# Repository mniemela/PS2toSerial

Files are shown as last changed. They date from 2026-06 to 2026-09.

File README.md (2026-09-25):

# PS2toSerial
PS/2 to serial converter using ATtiny4313 and MAX232. There are plenty of similar projects, but almost all of them are external, so here's my internal version
which draws power from floppy power connector.

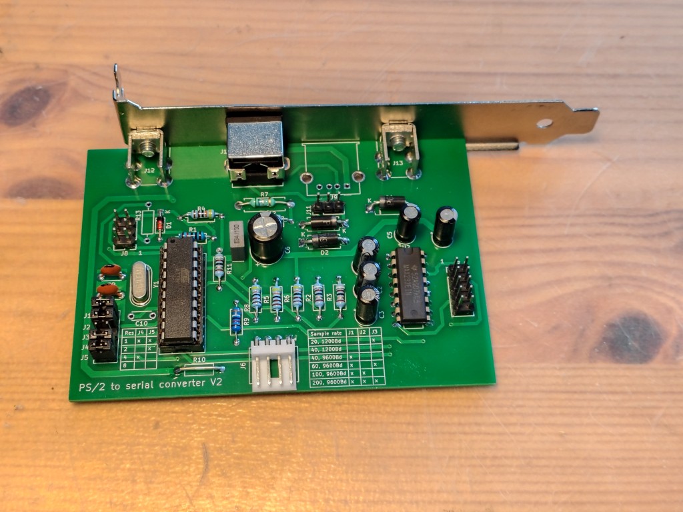
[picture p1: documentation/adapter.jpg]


## Description

This does essentially the same thing as other PS/2 to serial adapters: it interfaces with PS/2 mouse, and pretends to be a serial mouse to the computer.

It has following features:
* Support for normal 1200 baud serial, or 9600 baud high speed mode
* Support for wheel mouse
* Sample rate is selected from 20/40/60/100/200 with jumpers. For higher than 40, 9600 baud serial is needed.
* Resolution is configured with jumpers
* Option for USB A connector, so no need for a passive USB->PS/2 -adapter
* Option for PS/2 connector is also provided
* Supports hotplugging
* Crystal oscillator for ensuring accurate baud rate
* TVS diodes for ESD protection
* Overcurrent protection using ATtiny4313's onboard analog comparator and a P-type MOSFET as a switch
* No SMD components, so it's easy to assemble
* Programming via SPI header
* Supports combining movement packets in 1200 baud mode as a KVM workaround

Jumpers J1 sets baud rate, closed is high speed mode. J2 and J3 sets sample rate as described in silkscreen, and J4 and J4 set resolution.

Using 9600 baud serial speed requires modified mouse drivers, which can be found for example from this project:
https://github.com/LimeProgramming/USB-serial-mouse-adapter/tree/main

There are footprints for both USB-A and mini-DIN6 or PS/2 connector, only one of them should be populated.

## KVM issues

Some KVM switches ignore commands to set sample rate. The adapter tries to set baud rate to configured value, but the KVM will ignore 
it and packets are received faster than they can be sent to PC. As a new feature, this adapter combines data in movement packets
so that they don't have to be dropped.

Also, some KVM switches randomly reset in middle of normal operation. There's a workaround for this as well.

## Technical details

ATtiny has both hardware USART and Universal Serial Interface or USI, which is readily adaptable to PS/2, so there's only minimal need for bit banging. USI provides 
start condition detector with interrupt and counter (increased at PS/2's clock rising and falling edge) overflow interrupt, which removes need for polling. Instead
of sampling data on falling clock edge, this adapter uses rising edge as all the devices I have measured change data line state closer to falling than rising edge.
In particular, with a KVM switch this was within as little as 3µs from falling edge!

Resistors R8 and R9 form voltage divider for analog comparator positive input pin. R7 is used as a shunt resistor for current detection, voltage after it goes to
comparator's negative input pin. Comparator's output is monitored by interrupt from timer 0 every 100µs, and if there's overcurrent for 1ms, power to PS/2 is shut down.

RTS and DTR signals to pins PB2 and PB3 are monitored with pin change interrupt. When either of them goes down and then back up, mouse detection characters are sent if
mouse is connected.

Normally PS/2 host doesn't know whether mouse is disconnected or is just still, so the adapter polls mouse by sending command enable data reporting or 0xF4 every two
seconds. If mouse is connected, it replys with an ACK or 0xFA, if it's disconnected, there's no clock signal which is detected.

Some KVM switches randomly reset in the middle of normal operation and send 0xAA and 0x00 as during boot, then stopping to send movement data. This adapter attempts
to detect this situation and recover from it.

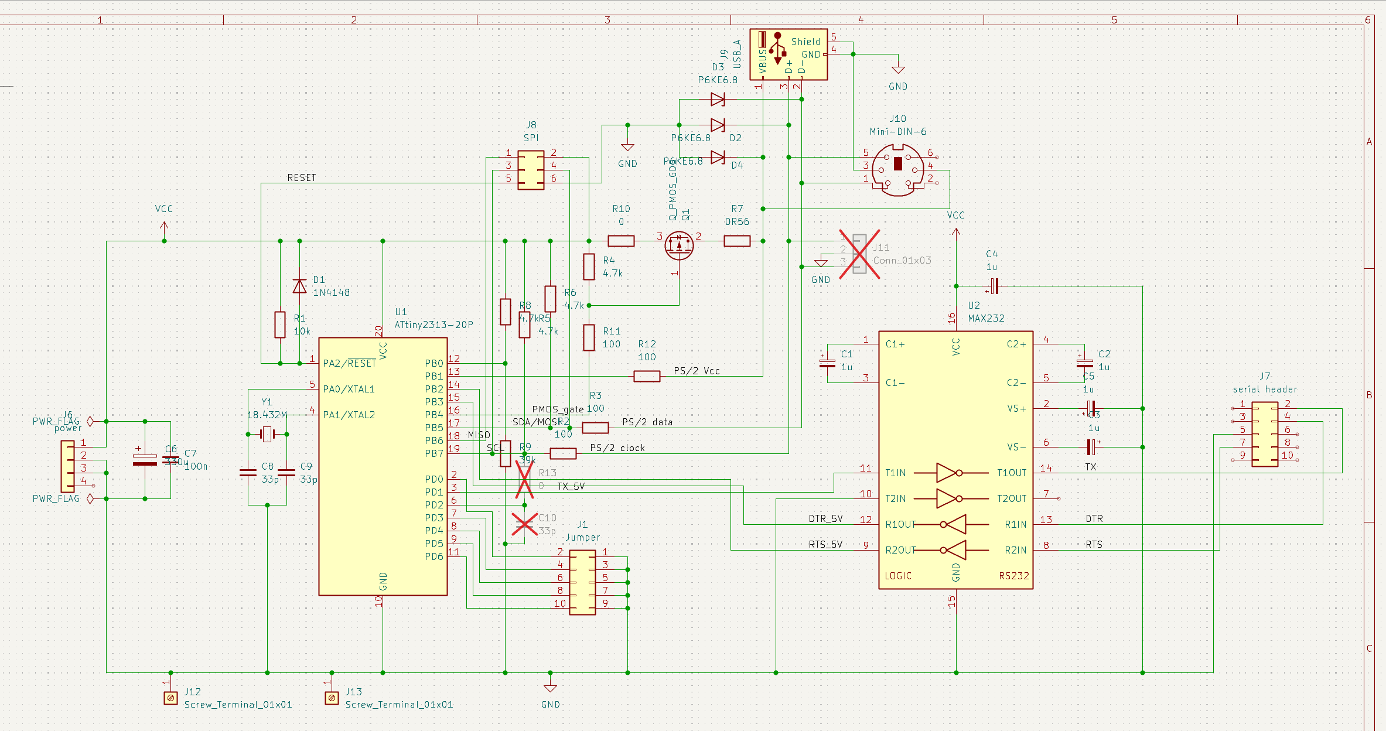
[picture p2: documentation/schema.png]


\
**BOM of specific components:**
| Ref. | Part. no. | Note |
|---|---|---|
| Q1 | MTD20P06HDL | Any DPAK logic level P-channel enhancement-type MOSFET with similar pinout will work. |
| U1 | ATtiny4313-PU | Microcontroller |
| U2 | MAX232 | RS-232 transceiver |
| R7 | 560mΩ resistor | Anything with max. dissipation > 600mW will work. |
| Y1 | AS-18.432-20 | Other frequencies up to 20M can be used, but will require modifications to software. |
| D2-D4 | P6KE6.8 | TVS diode with 5.8V working voltage |
| J10 | MDC-206 | mini-DIN6 connector |
| J12, J13 | AMT0440051DB0000G | M4 screw terminal |
| C6 | ??? | Exact value of this capacitor isn't important. |

## Building software and MCU fuse settings

This has been built with Microchip studio, currently there's no Makefile for other toolchains. When programming the MCU, fuses must also be set. Correct setting for
high fuse is 0xDF and for low fuse 0xFF.

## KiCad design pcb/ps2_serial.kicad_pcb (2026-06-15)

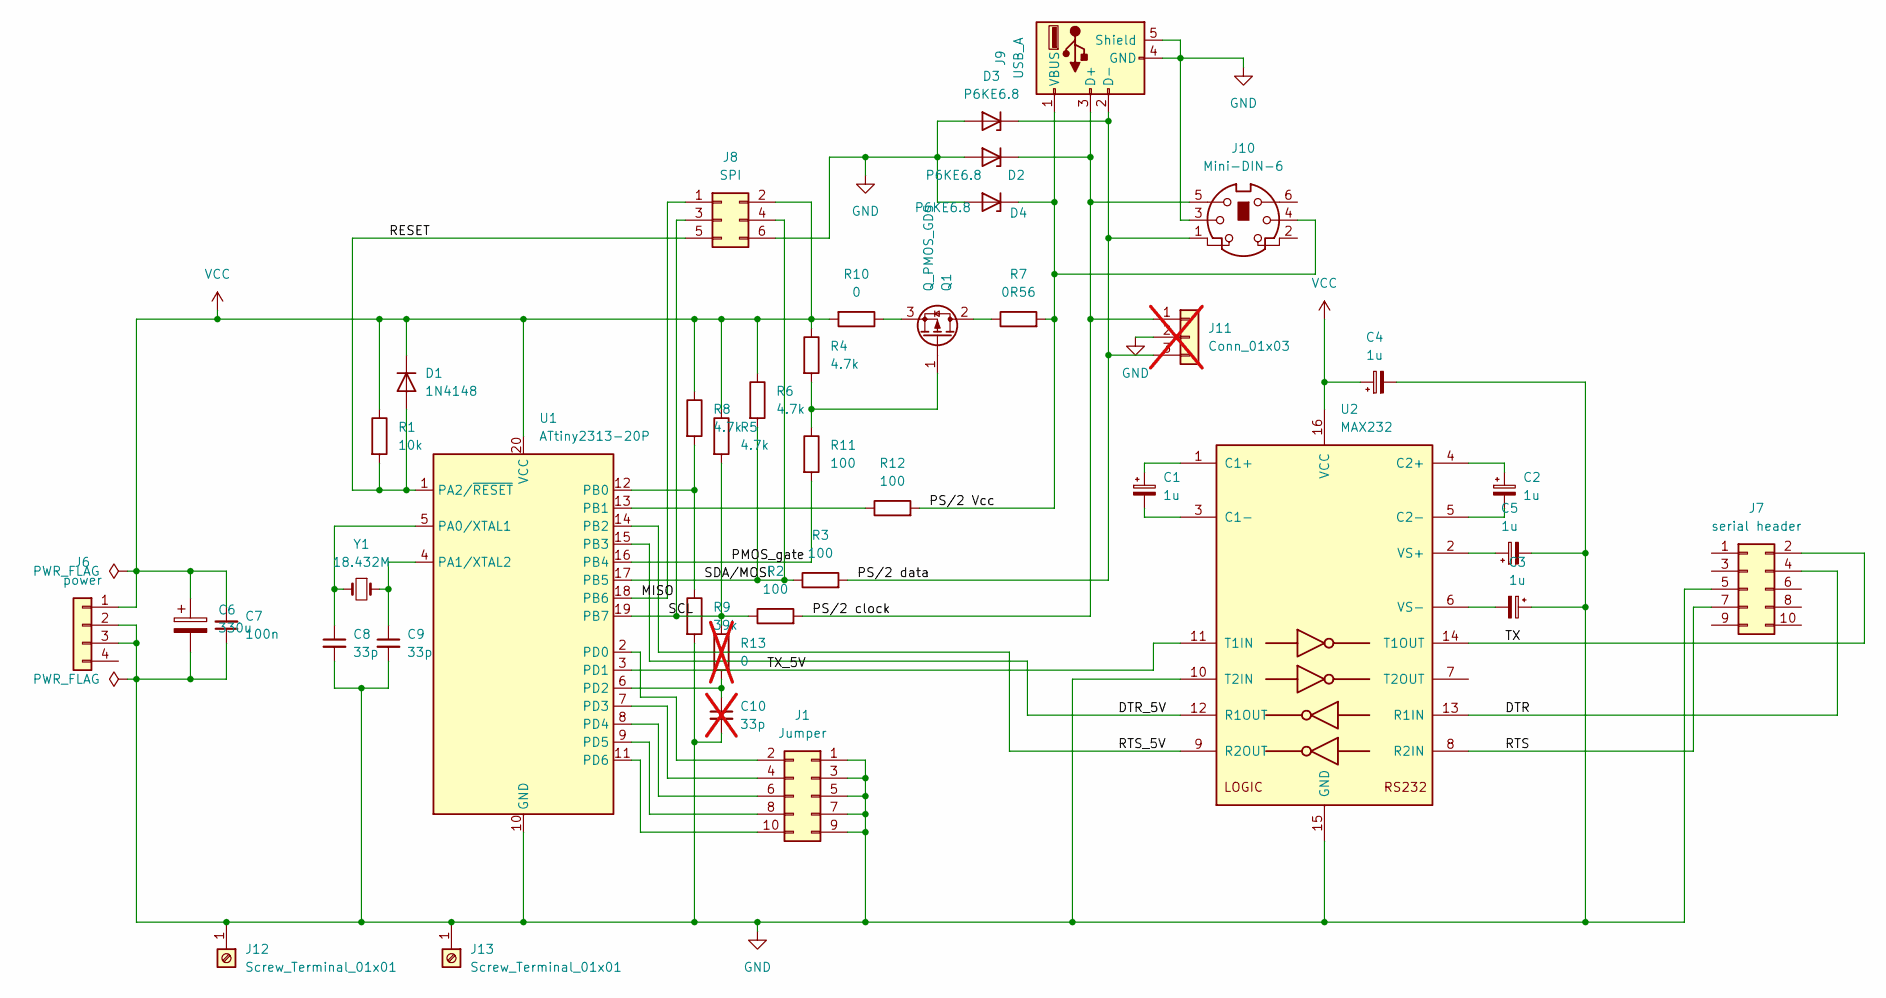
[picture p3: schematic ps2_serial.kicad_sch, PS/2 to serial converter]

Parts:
C1, C2, C3, C4, C5: 1u; CP_Radial_D5.0mm_P2.50mm
C6: 330u; CP_Radial_D8.0mm_P3.50mm
C7: 100n; C_Rect_L7.0mm_W2.5mm_P5.00mm
C8, C9: 33p; C_Disc_D4.3mm_W1.9mm_P5.00mm
C10: 33p; C_Disc_D4.3mm_W1.9mm_P5.00mm; not fitted
D1: 1N4148; D_DO-35_SOD27_P7.62mm_Horizontal
D2, D3, D4: P6KE6.8; D_DO-15_P10.16mm_Horizontal
J1: Jumper; PinHeader_2x05_P2.54mm_Vertical
J6: power; Molex_Nano-Fit_105313-xx04_1x04_P2.50mm_Horizontal
J7: serial header; PinHeader_2x05_P2.54mm_Vertical
J8: SPI; PinHeader_2x03_P2.54mm_Vertical
J9: USB_A; USB_A_Molex_67643_Horizontal
J10: Mini-DIN-6; J_Mini-DIN-6
J11: Conn_01x03; PinHeader_1x03_P2.54mm_Vertical; not fitted
J12, J13: Screw_Terminal_01x01; Amphenol_M4-44051DB
Q1: Q_PMOS_GDS; TO-252-2
R1: 10k; R_Axial_DIN0207_L6.3mm_D2.5mm_P10.16mm_Horizontal
R2, R3, R11, R12: 100; R_Axial_DIN0207_L6.3mm_D2.5mm_P10.16mm_Horizontal
R4, R5, R6, R8: 4.7k; R_Axial_DIN0207_L6.3mm_D2.5mm_P10.16mm_Horizontal
R7: 0R56; R_Axial_DIN0411_L9.9mm_D3.6mm_P12.70mm_Horizontal
R9: 39k; R_Axial_DIN0207_L6.3mm_D2.5mm_P10.16mm_Horizontal
R10: 0; R_Axial_DIN0207_L6.3mm_D2.5mm_P10.16mm_Horizontal
R13: 0; R_Axial_DIN0207_L6.3mm_D2.5mm_P10.16mm_Horizontal; not fitted
U1: ATtiny2313-20P; DIP-20_W7.62mm_Socket_LongPads
U2: MAX232; DIP-16_W7.62mm_LongPads
Y1: 18.432M; Crystal_HC49-U_Vertical

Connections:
/DTR: J7.4, U2.13 (R1IN)
/DTR_5V: U1.15 (PB3), U2.12 (R1OUT)
/MISO: J8.1, U1.18 (PB6)
/PMOS_gate: R11.2, U1.16 (PB4)
/PS/2 Vcc: D4.1 (K), J9.1 (VBUS), J10.4, R7.2, R12.2
/PS/2 clock: D2.1 (K), J9.3 (D+), J10.5, J11.1, R2.2
/PS/2 data: D3.1 (K), J9.2 (D-), J10.1, J11.3, R3.2
/RESET: D1.2 (A), J8.5, R1.2, U1.1 (PA2/~RESET)
/RTS: J7.7, U2.8 (R2IN)
/RTS_5V: U1.14 (PB2), U2.9 (R2OUT)
/SCL: J8.3, R2.1, R5.2, R13.1, U1.19 (PB7)
/SDA/MOSI: J8.4, R3.1, R6.2, U1.17 (PB5)
/TX: J7.2, U2.14 (T1OUT)
/TX_5V: U1.3 (PD1), U2.11 (T1IN)
GND: C3.1, C4.2, C5.2, C6.2, C7.1, C8.2, C9.2, C10.2, D2.2 (A), D3.2 (A), D4.2 (A), J1.1, J1.3, J1.5, J1.7, J1.9, J6.2, J6.3, J7.5, J8.6, J9.4 (GND), J9.5 (Shield), J10.3, J10.C1, J10.C2, J10.SH, J11.2, J12.1, J13.1, R9.2, U1.10 (GND), U2.10 (T2IN), U2.15 (GND)
unnamed: J1.2, U1.2 (PD0)
unnamed: J1.4, U1.7 (PD3)
unnamed: J1.6, U1.8 (PD4)
unnamed: J1.8, U1.9 (PD5)
unnamed: J1.10, U1.11 (PD6)
unnamed: Q1.2 (D), R7.1
unnamed: Q1.1 (G), R4.2, R11.1
unnamed: Q1.3 (S), R10.1
unnamed: C8.1, U1.5 (PA0/XTAL1), Y1.2
unnamed: C9.1, U1.4 (PA1/XTAL2), Y1.1
unnamed: R8.2, R9.1, U1.12 (PB0)
unnamed: R12.1, U1.13 (PB1)
unnamed: C10.1, R13.2, U1.6 (PD2)
unnamed: C1.1, U2.1 (C1+)
unnamed: C1.2, U2.3 (C1-)
unnamed: C2.1, U2.4 (C2+)
unnamed: C2.2, U2.5 (C2-)
unnamed: C5.1, U2.2 (VS+)
unnamed: C3.2, U2.6 (VS-)
VCC: C4.1, C6.1, C7.2, D1.1 (K), J6.1, J8.2, R1.1, R4.1, R5.1, R6.1, R8.1, R10.2, U1.20 (VCC), U2.16 (VCC)

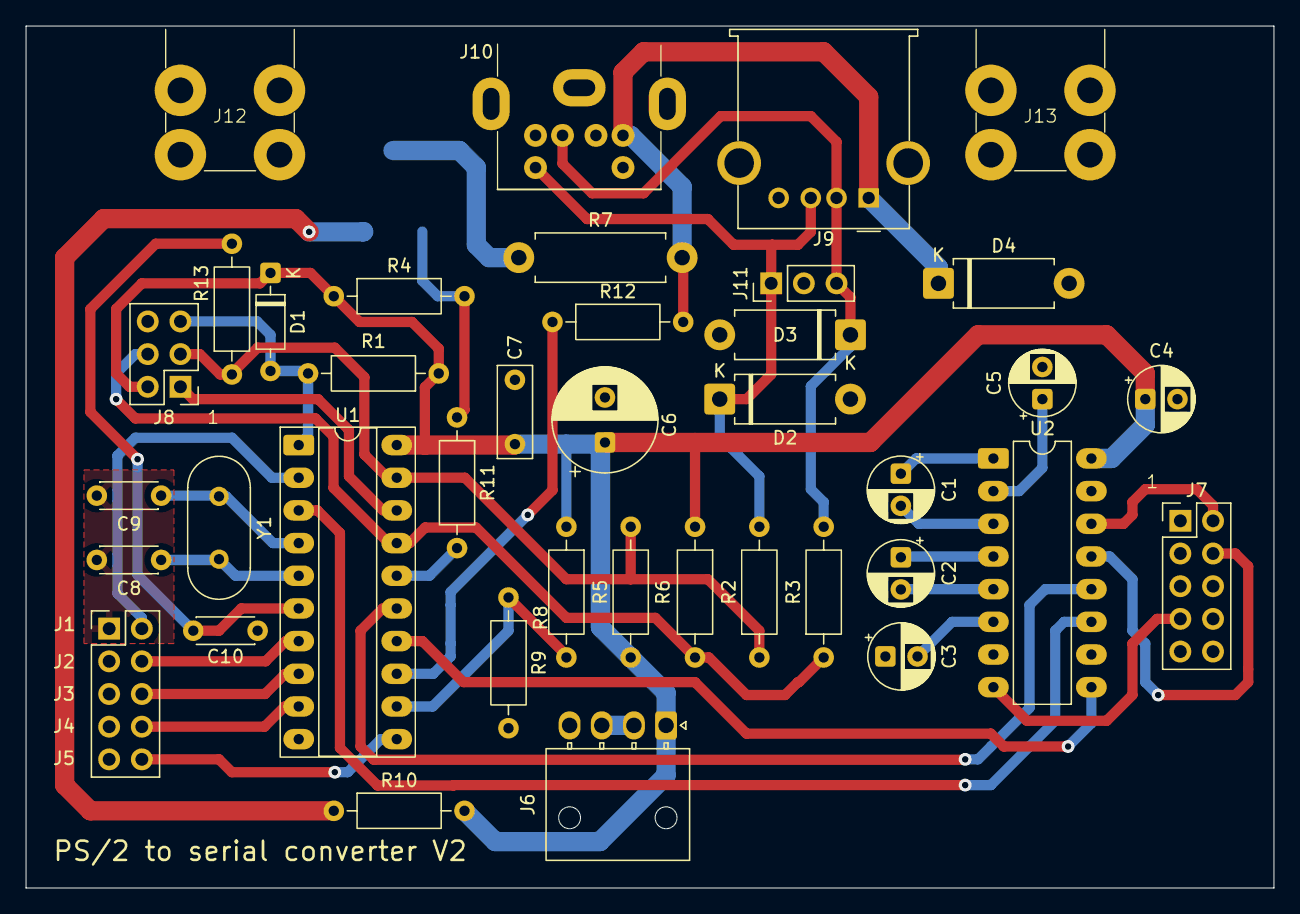
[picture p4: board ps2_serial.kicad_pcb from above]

Board: 2 copper layers, 97.0 x 67.0 mm, 40 parts (1 on the bottom side), 35 nets.

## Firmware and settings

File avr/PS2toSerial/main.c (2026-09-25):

/*
 * PS2toSerial.c
 *
 * Created: 3.1.2026 8.05.48
 * Author : Mikael Niemelä
 */

#include <avr/io.h>
#include <avr/interrupt.h>
#include <inttypes.h>

#include "constants.h"
#include "ps2.h"
#include "uart.h"
#include <util/delay.h>

void init() {
	
	//turn on pullups for jumpers and unused pins
	PORTD = ~(1<<PD1);
	PORTB = 1 << PB6;
	
	//turn off comparator digital inputs
	DIDR = (1<<AIN1D) | (1<<AIN0D);
	
	_delay_us(100);
	
	// check jumpers for sample rate and baud rate
	uint8_t sampleRate = 0;
	uint8_t highSpeedUart = !((1 << PIND0) & PIND);
	if (highSpeedUart) {
		if (((1 << PIND3) & PIND) && ((1 << PIND4) & PIND) )
			sampleRate = 40;
		else if ((1 << PIND3) & PIND)
			sampleRate = 60;
		else if ((1 << PIND4) & PIND)
			sampleRate = 100;
		else
			sampleRate = 200;
	} else {
		if ((1 << PIND4) & PIND)
			sampleRate = 40;
		else
			sampleRate = 20;
	}
	
	//check jumpers for resolution
	uint8_t resolution = (((1 << PIND5) | (1 << PIND6)) & PIND) >> 5;
	
	
	uart_init(highSpeedUart);
	ps2_init(sampleRate, resolution, highSpeedUart);
	
	//turn on device power
	DDRB = 1<<PB4;
	
	//init timer0 for interrupt every 100µs
	OCR0A = (uint8_t)((F_CPU) * 0.0001 / 8 + 0.5);
	TCCR0A = (1 << COM0A1) | (1 << WGM01);
	TCCR0B = 1 << CS01;
	TIMSK |= (1 << OCIE0A);
	
	//init pin change interrupt for detecting RTS or DTR low
	PCMSK = (1<<PCINT2) | (1<<PCINT3);
	GIMSK = 1<<PCIE0;

	sei();
}

int main(void)
{
    init();
	
    while (1) 
    {
    }
}

ISR(PCINT0_vect) {
	//send detection characters when RTS or DTR goes back up
	static uint8_t previousState = 0;
	uint8_t currentState = PINB & ((1<<PB2) | (1<<PB3));
	uint8_t dtrValue = currentState & (1<<PB3);
	uint8_t rtsValue = currentState & (1<<PB2);
	if ((!dtrValue && (previousState & (1<<PB3))) || (!rtsValue && (previousState & (1<<PB2)))) {
		char mouseType = getMouseType();
		if (mouseType) {
			addTxData('M');
			addTxData(mouseType);
			//send fake PnP package, looks like this is required by MS wheel mouse driver
			addTxData(0x08);
			addTxData(0x09);
			startTx();
		}
	}
	if (currentState != previousState)
		previousState = currentState;
}

ISR(TIMER0_COMPA_vect) {
	//don't do anything if power is already off
	if (PORTB & (1<<PB4))
		return;
	
	// increase counter when comparator output is on, otherwise decrement (until 0)
	static uint8_t counter = 0;
	if (ACSR & (1 << ACO)) {
			counter++;
		} else {
		if (counter > 0)
			counter--;
	}
	
	// turn power off after 1ms of overcurrent
	if (counter > 10)
		PORTB = PORTB | (1<<PB4);
}

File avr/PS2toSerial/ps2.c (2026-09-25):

/*
 * ps2.c
 *
 * Created: 4.1.2026 14.05.25
 *  Author: Mikael Niemelä
 */ 


#include <avr/io.h>
#include <avr/interrupt.h>
#include <util/parity.h>

#include "ps2.h"
#include "uart.h"
#include "constants.h"
#include <util/delay.h>

#include "ringbuf.h"

char ps2TxBuf_array[PS2_TX_BUF_SIZE];
char rxArray[4];

struct ringBuffer ps2TxBuf;

static void (*handleOverflow)();
static void (*handleRxByte)(char);

static void handleRx();
static void handleResponse(char);

static char mouseType = 0;
static uint8_t firstByteReceived = 0;
static char parityAndStopBits;
static char previousSentByte;
static uint8_t bytesReceived = 0;
static uint8_t sampleRate = 0;
static uint8_t resolution = 0;
static uint8_t highSpeedUart = 0;

volatile static uint8_t mergePackets = 0;
static char previous4thByte = 0;
volatile static uint8_t previousButtons = 0;
volatile static uint16_t previousXMovement = 0;
volatile static uint16_t previousYMovement = 0;
volatile static uint8_t previousZMovement = 0;

static inline char reverse(char byte) {
	uint8_t maskUp = 0x01;
	uint8_t maskDown = 0x80;
	uint8_t result = 0;
	for (; maskDown; maskDown >>= 1, maskUp <<= 1) {
		if (byte & maskUp)
			result |= maskDown;
	}
	return result;
}

static inline int8_t convertTo8Bit2sComplement(uint8_t sign, uint8_t value) {
	if (sign) {
		if (value & 0x80) {
			return (int8_t)value;
		}
		else {
			return -127;
		}
	}
	else if (value > 127) {
		return 127;
	}
	else {
		return (int8_t)value;
	}
}

static inline int8_t truncateTo8BitInt(int16_t value) {
	if (value > 127) {
		return 127;
	}
	else if (value < -127) {
		return -127;
	}
	else {
		return (int8_t)value;
	}
}

//wheel movement is represented by 4 bit int
static inline char truncateTo4BitInt(int8_t value) {
	if (value > 7)
		value = 7;
	else if (value < -8)
		value = -8;
	return (((uint8_t)value & 0x80) >> 4) | ((uint8_t)value & 0x0F);
}

static void sendPacket(uint8_t buttons, int8_t xMovement, int8_t yMovement, uint8_t asCallback) {

	//enable interrupts so that this won't mess up anything timing-critical
	sei();

	if (mergePackets) {
		buttons |= previousButtons;
		xMovement = truncateTo8BitInt(previousXMovement + xMovement);
		yMovement = truncateTo8BitInt(previousYMovement + yMovement);
		previousXMovement = 0;
		previousYMovement = 0;
		if (mouseType == '3')
			previousButtons = 0;
	}
	
	char byte1 = (1<<6) | ((buttons & 0x01)<<5) | ((buttons & 0x02)<<3) | (((char)yMovement & 0xC0)>>4) | (((char)xMovement & 0xC0)>>6);
	char byte2 = xMovement & 0x3F;
	char byte3 = yMovement & 0x3F;
	char byte4 = (buttons & 0x04) << 3;
	
	addTxData(byte1);
	addTxData(byte2);
	addTxData(byte3);
			
	if (mouseType == '3' && (byte4 || previous4thByte)) {
		addTxData(byte4);
		previous4thByte = byte4;
	}
	else if (mouseType == 'Z' && asCallback) {
		// need to add fourth packet if using wheel mouse
		addTxData(byte4 | truncateTo4BitInt(previousZMovement));
		previousZMovement = 0;
		previousButtons = 0;
	}
	startTx();
	setCallback(0);
	mergePackets = 0;
}

static void handleStream(char c) {
	rxArray[bytesReceived] = c;
	bytesReceived++;
	static uint8_t skipped = 0;
	if (bytesReceived == 2 && rxArray[0] == 0xAA && rxArray[1] == 0) {
		//this is a workaround for KVM switches that apparently decide to
		//regularly reset in the middle of normal operation.
		//in theory these could be part of a normal movement packet,
		//so we need to wait a bit to see whether next byte comes
		
		TIFR |= 1 << OCF1B;
		TIMSK |= 1 << OCIE1B;
	}
	else if (bytesReceived == 3) {
		//disable interrupt for KVM workaround
		TIMSK &= ~(1 << OCIE1B);
		
		if (mouseType == '3') {
			// no fourth byte coming if not wheeled mouse
			bytesReceived = 0;
		}
		
		// if movement is too large, just use maximum value that fits (two's complement!)
		uint8_t xSign = rxArray[0] & 0x10;
		uint8_t ySign = rxArray[0] & 0x20;
		int8_t xMovement = convertTo8Bit2sComplement(xSign, rxArray[1]);
		int8_t yMovement = convertTo8Bit2sComplement(ySign, rxArray[2]) * -1;
		uint8_t buttons = (rxArray[0] & 0x01) | (rxArray[0] & 0x02) | (rxArray[0] & 0x04);
		
		// some KVM switches ignore command to set sample rate and buffer can get full in
		// 1200 baud mode. combine several packets into one in that case
		if (!highSpeedUart && (mergePackets || (getUsedBuffer() > 0))) {
			previousXMovement += xMovement;
			previousYMovement += yMovement;
			previousButtons |= buttons;
			mergePackets = 1;
			skipped = 1;
			// a callback is needed so that the last packet will be sent after tx is complete
			setCallback(&sendPacket);
		}
		else {
			sendPacket(buttons, xMovement, yMovement, 0);
		}
	}
	else if (bytesReceived == 4) {
		bytesReceived = 0;
		
		// it's possible that wheel movement data is lost if the packet had been sent to serial
		// after 3rd byte had been received but before 4th byte arrived. this can happen only
		// when merging packets as a KVM workaround
		if (skipped) {
			int8_t wheelMovement = 0;
		
			//convert to int8_t
			if (rxArray[3] & 0xF8)
				wheelMovement = (int8_t)(0xF8 | (rxArray[3] & 0x07));
			else
				wheelMovement = (int8_t)(rxArray[3] & 0x07);
			previousZMovement += wheelMovement;
			skipped = 0;
			return;
		}
		
		char byte4 = (((rxArray[0] | previousButtons) & 0x04) << 2) | (rxArray[3] & 0x0F);
		previousZMovement = 0;
		addTxData(byte4);
		startTx();
	}
}

static inline void clearFlagsEnableStartConditionDetection() {
	USISR = (1<<USISIF) | (1<<USIOIF);
	USICR = (1<<USISIE) | (1<<USIWM1) | (1<<USICS1);
}

static inline void waitUntilPinDown(uint8_t mask) {
	uint8_t timeOut = 255;
	do {
		_delay_us(1);
		timeOut--;
	}
	while (timeOut && (PINB & mask));
}

static void handleTxEnd() {
	//release SDA
	DDRB = DDRB & ~(1<<PB5);
	
	//disable overflow and start condition interrupts, enable interrupts for other stuff
	USICR = (1<<USIWM1) | (1<<USICS1);
	sei();
	
	// wait so that SDA has had time to rise
	_delay_us(5);
	
	//wait until SDA low
	waitUntilPinDown(1<<PB5);
	
	//wait until SCL low
	waitUntilPinDown(1<<PB7);
	
	//wait until SDA and SCL released
	for(uint8_t i = 0; i<255; i++) {
		_delay_us(1);
		if ((PINB & (1<<PB5)) && (PINB & (1<<PB7))) {
			break;
		}
	}
	
	clearFlagsEnableStartConditionDetection();
}

static void handleTx2ndByte() {
	USIDR = parityAndStopBits;
	//set counter so it overflows after remaining bits and clear overflow flags
	USISR = (1<<USISIF) | (1<<USIOIF) | 13;
	handleOverflow = &handleTxEnd;
}
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

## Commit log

2026-02-23 First version.
    [ps2_serial.kicad_pcb, ps2_serial.kicad_sch]
2026-02-26 Fixed compatibility issues with KVM switch and improved documentation.
    [ps2.c]
2026-05-26 Added workaround for KVM switches that reset in the middle of normal operation.
    [ps2.c]
2026-06-15 V2 for PCB. Implemented following changes: -more elegant mounting mechanism -more jumper settings -footprint for both USB and PS/2 socket -reservation for using INT0 to trigger SDA sampling -smaller 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
    [ps2_serial.kicad_pcb, ps2_serial.kicad_sch]
2026-06-15 Implemented changes for handling jumpers in new PCB and changed clock macro.
2026-08-23 Fixed fuse settings missing from documentation and added gerbers and binaries to repo.
2026-09-25 Implemented a feature to combine movement packets to improve compatibility with KVM switches that ignore sample rate setting.
